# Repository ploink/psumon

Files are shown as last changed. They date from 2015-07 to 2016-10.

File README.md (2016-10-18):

# PSUmon
PSUmon is a low-cost hardware ATX power supply monitor. 
It hotplugs to any free SATA power connector and signals if voltage or ripple exceeds the ATX specification.

The PCB is designed using Eagle 5, but should import ok in version 6 and 7. 
The board is very small, so the freeware edition of eagle can be used.
The firmware for the ATtiny24A microcontroller is written in C using Atmel Studio. An ISP header is included for in-system programming and debugging.

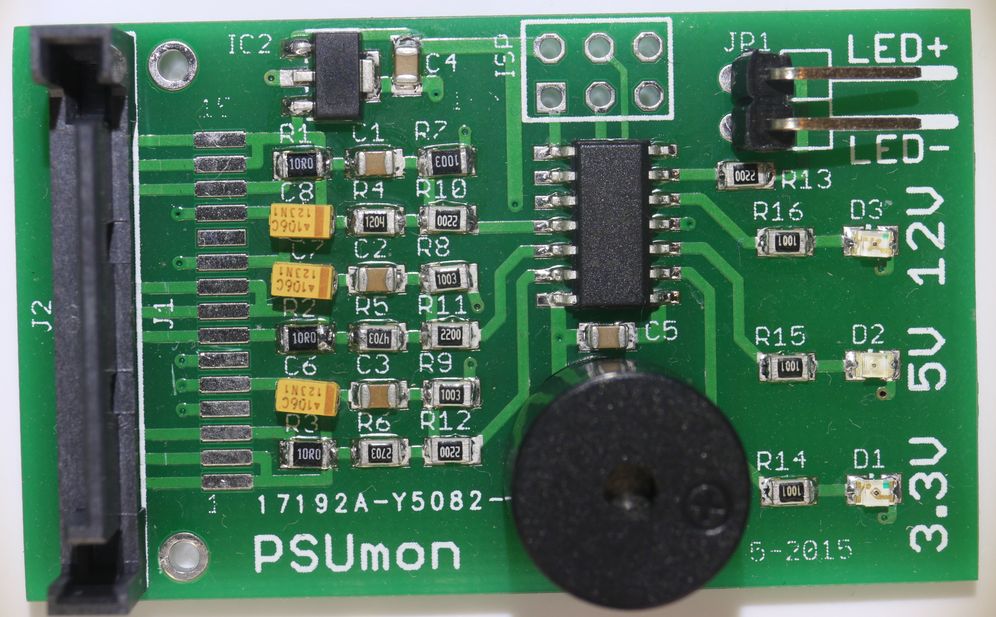
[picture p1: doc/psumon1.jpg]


Voltage tresholds are:

|Voltage |Tolerance |Ripple |LED color |
|---|---|---|---|
|3.3V | ±5% | 50mV  |GREEN |
|5V | ±5% | 50mV  |RED |
|12V | ±5% |120mV  |YELLOW |

This is how it works:
* When voltage and ripple are within limits, the corresponding LED lights continuously.
* When voltage or ripple exceeds the limit once, it blinks once every 3 seconds or so.
* When it exceeds the limit twice it blinks twice, ... and so on, up to 5x.
* When any led blinks 3x or more, the buzzer beeps 1x or more.
* The 3.3V power may not be present on every connector, in that case the green LED will be off and the voltage is ignored.
* There is a header to connect an optional external LED, for example your system power LED. It signals the worst of the three voltages.

## Parts and schematic
Most parts and values are obvious from <a href="https://raw.githubusercontent.com/ploink/psumon/master/doc/circuit.png">the schematic</a> and can be exported to a text file from within Eagle. If you want to check the gerber files, just open top.gvp and bottom.gvp in <a href="http://gerbv.geda-project.org/">gerbv</a>.

Note that the included parts.txt and also the gerber files may not be up to date!

The design includes two options for a <a href="https://raw.githubusercontent.com/ploink/psumon/master/doc/sata.jpg">SATA power connector</a>. A suitable connector with only power and no data connection is hard to find. I got mine from seller CASIBAO LED LIGHT on Aliexpress, but that is no longer available, but <a href="https://www.aliexpress.com/item/Original-new-100-SATA-interface-hard-disk-interface-socket-15P-male-180-degree-line-of-single/32738192943.html">this one</a> from Shenzhen MingSheng International Trading Co., Ltd. seems to be the same. You can also get <a href="http://www.ebay.com/itm/10-Pcs-7-15-Pin-Right-Angle-SMT-Male-Sata-Connector-For-2-5-Hard-Drive-HDD-/171720426198">this 7+15pin connector</a> from seller newdeparture2010 on Ebay and simply <a href="https://raw.githubusercontent.com/ploink/psumon/master/doc/psumon2.jpg"> cut the data connector off</a>.

To measure the voltages, the DC levels are divided down using a resistive divider to get them within range of the 1.1V reference from the ATtiny24A MCU. Using a capacitor, the AC ripple voltages are coupled directly to the same MCU pins to get a better sensitivity. This means the firmware needs to average to get the DC level and determine min/max values to get the ripple.

The 78L05 (IC2) is to make sure the MCU gets a stable 5V power even if the DUT (device under test) is very bad.

Do NOT replace the three tantalum capacitors with ceramics. The ESR is important for suppressing high frequency resonance in the power cable, but you may want to add a 100nF ceramic in parallel as is required in the <a href="http://www.formfactors.org/developer/specs/atx12v%20psdg2.01.pdf">ATX PSU design guide (pdf)</a> section 3.2.6.

## Calibration
The firmware has a provision for calibration. All you need to do after programming is to connect it to a reference supply for the first time and it wil measure and store the reference values. The PSU in one of my computers is accurate to about 1.5% so I just used that, but if you plan to sell this product, you should really make a good calibration setup.

Note that even when you use precision resistors, the 1.1V reference inside the MCU is really not accurate enough to skip the calibration step!

## To wrap it up
It is strongly recommended to protect the PCB from shorts inside your computer case. Wrapping it in 30mm diameter transparant heatshrink tubing will do the job.

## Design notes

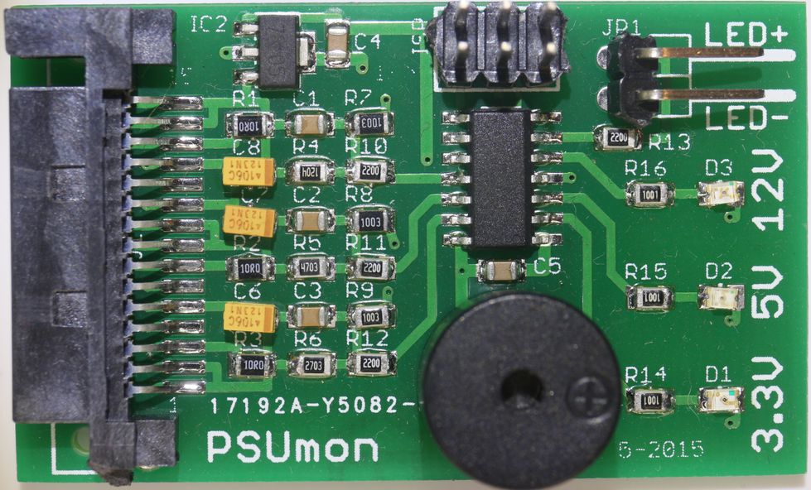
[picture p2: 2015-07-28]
doc/psumon2.jpg

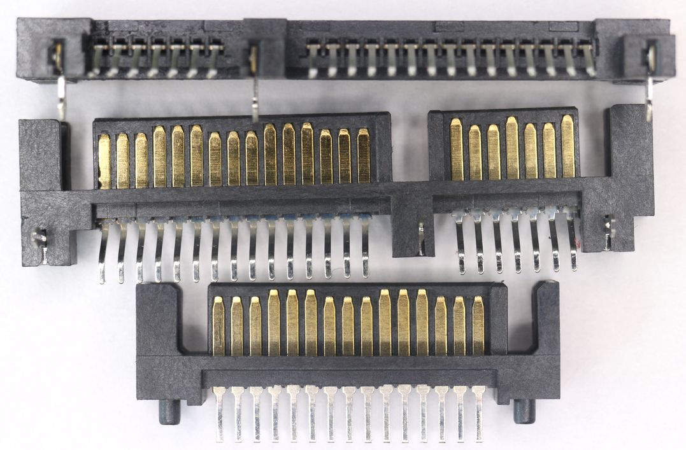
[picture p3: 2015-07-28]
doc/sata.jpg

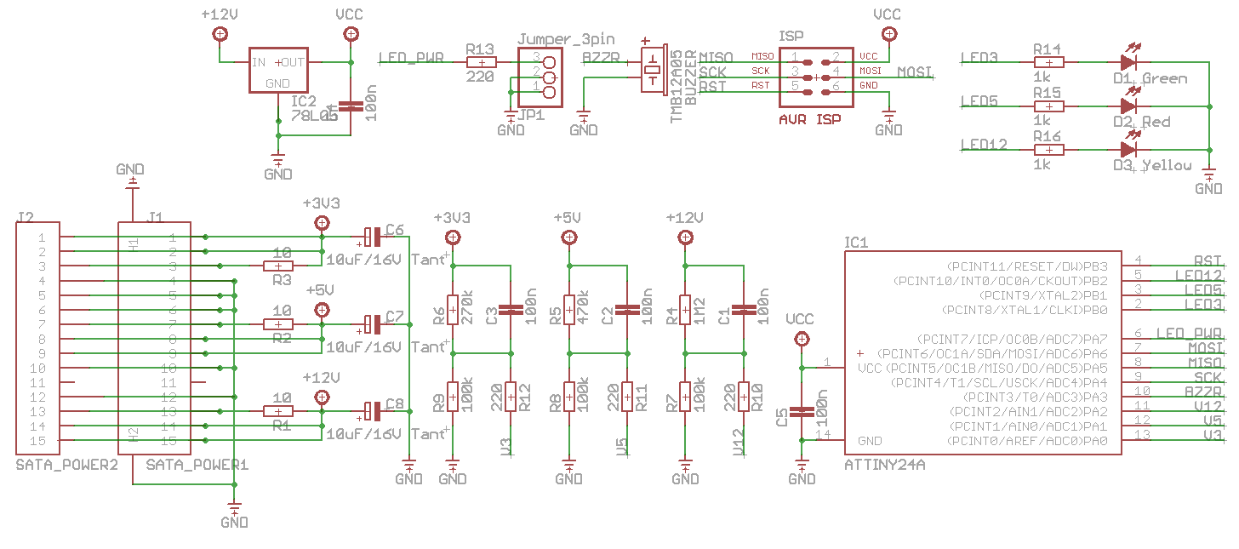
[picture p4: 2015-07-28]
doc/circuit.png

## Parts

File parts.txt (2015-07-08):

Partlist

Exported from psumon.brd at 08-07-2015 23:53:47

EAGLE Version 5.12.0 Copyright (c) 1988-2011 CadSoft

Part     Value          Package       Library  Position (mil)        Orientation

BUZZER   TMB12A05       BUZZER_12_7.6 psumon   (1200.787 246.063)    R180
C1       100n           C0805         psumon   (738.189 885.827)     R180
C2       100n           C0805         psumon   (738.189 649.606)     R180
C3       100n           C0805         psumon   (738.189 413.386)     R180
C4       100n           C0805         psumon   (826.772 1082.677)    R90
C5       100n           C0805         psumon   (1205.906 523.228)    R0
C6       10uF/16V Tant  C1206P        psumon   (570.866 413.386)     R180
C7       10uF/16V Tant  C1206P        psumon   (570.866 649.606)     R180
C8       10uF/16V Tant  C1206P        psumon   (570.866 767.717)     R180
D1       Green          D0805         psumon   (1732.283 196.85)     R0
D2       Red            D0805         psumon   (1732.283 413.386)    R0
D3       Yellow         D0805         psumon   (1732.283 629.921)    R0
IC1      ATTINY24A      SOIC14        psumon   (1209.449 750.394)    R90
IC2      78L05          SOT89         psumon   (651.575 1063.386)    R270
ISP      AVR-ISP-6VERT  AVR-ISP-6     psumon   (1200.787 1062.992)   R0
J1       SATA_POWER1    SATA_POWER1   psumon   (413.78 590.551)      R270
J2       SATA_POWER2    SATA_POWER2   psumon   (167.323 590.551)     R90
JP1      Jumper_3pin    1X03/90       psumon   (1653.543 984.252)    R270
R1       10             R0805         psumon   (590.551 885.827)     R180
R2       10             R0805         psumon   (590.551 531.496)     R180
R3       10             R0805         psumon   (590.551 295.276)     R180
R4       1M2            R0805         psumon   (738.189 767.717)     R180
R5       470k           R0805         psumon   (738.189 531.496)     R180
R6       270k           R0805         psumon   (738.189 295.276)     R180
R7       100k           R0805         psumon   (885.827 885.827)     R180
R8       100k           R0805         psumon   (885.827 649.606)     R180
R9       100k           R0805         psumon   (885.827 413.386)     R180
R10      220            R0805         psumon   (885.827 767.717)     R0
R11      220            R0805         psumon   (885.827 531.496)     R0
R12      220            R0805         psumon   (885.827 295.276)     R0
R13      220            R0805         psumon   (1574.803 748.031)    R0
R14      1k             R0805         psumon   (1574.803 196.85)     R0
R15      1k             R0805         psumon   (1574.803 413.386)    R0
R16      1k             R0805         psumon   (1574.803 629.921)    R0

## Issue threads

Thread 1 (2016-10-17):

Sata Power Connector Link

carlossless, 2016-10-17:
Hi, Awesome project. I've stumbled across it while looking for a SMD or through-hole SATA Power Connector (with no data). Yes the ones you mentioned are hard to find ;). The link you have on the readme no longer works and 404s. Did you happen to maybe find another source for these rare parts, and if so could you share them again?

Thank you!

ploink, 2016-10-18:
Hi Karolis,

I have no other source for the connector, but searching Aliexpress.com
for "sata 15p power connector" I found some, though they have the 3
contacts for each power rail merged in one pin.
https://www.aliexpress.com/item/10pcs-lot-SATA-connector-power-Interface-SATA-15P-welding-seat-SATA-plastic-shell/32710552274.html

The other option is cutting of the data part from this connector. It is
a bit of a hack, but I it works very well.
http://www.ebay.com/itm/10-Pcs-7-15-Pin-Right-Angle-SMT-Male-Sata-Connector-For-2-5-Hard-Drive-HDD-/171720426198

Best regards,
Joost.

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

--
Joost Ruijsch
Rustenburg 22
6701DV Wageningen
0317-424249
06-19752562

carlossless, 2016-10-18:
Yep, after looking again with those exact keywords I found a bunch more. Including these ones: https://www.aliexpress.com/item/10PCS-Hard-disk-interface-SATA-15P-male-connector-socket-insert-plate-90-degrees/32706493159.html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
and
https://www.aliexpress.com/item/Original-new-100-SATA-interface-hard-disk-interface-socket-15P-male-180-degree-line-of-single/32738192943.html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,searchweb201602_2_10065_10068_10069_10017_10080_10082_10081_10060_10061_10062_10056_10037_10055_10054_10033_10059_10078_10079_10073_10070_421_420_10052_10053_10050_10051,searchweb201603_7&btsid=5557b6b3-ce7a-444c-99e0-0176f6f2e174

One of them is probably compatible with the footprint you have on this board.

ploink, 2016-10-18:
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
Yes the second one looks identical to mine. I have updated the readme,
thanks.

Joost Ruijsch

carlossless, 2016-10-19:
Thank you! Closing this issue.

Closed 2016-10-19.

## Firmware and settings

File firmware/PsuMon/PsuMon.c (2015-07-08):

/*
 * PsuMon.c
 *
 * Created: 15-05-2015 15:36:21
 *  Author: joost
 */ 

#define F_CPU 8000000UL

#include <avr/io.h>
#include <util/delay.h>
#include <avr/eeprom.h>
#include "bits.h"

const char fusedata[] __attribute__ ((section (".fuse"))) = {0xE2, 0xDC, 0xFF};

byte EEMEM EE_REF3=0xff;
byte EEMEM EE_REF5=0xff;
byte EEMEM EE_REF12=0xff;


#define	LED_3V	BIT(PORTB,0)
#define	LED_5V	BIT(PORTB,1)
#define	LED_12V	BIT(PORTB,2)
#define LED_PWR	BIT(PORTA,7)
#define BUZZER	BIT(PORTA,3)
	
#define MUX_3V		0b10000000
#define MUX_5V		0b10000001
#define MUX_12V		0b10000010
#define StartADC(x)	ADMUX=MUX_##x;BIT(ADCSRA,ADSC)=1
#define GetADC(x)	while (BIT(ADCSRA,ADSC)); x=ADCH;


// Calculated calibration values. These should work OK if you are lucky
byte REF3	 =  3.3*(100.0/(100+270))*255/1.1;
byte REF5	 =  5.0*(100.0/(100+470))*255/1.1;
byte REF12 =  12.0*(100.0/(100+1200))*255/1.1;

// Max ripple values.
static const byte RIPMAX3 = 0.050*255/1.1;
static const byte RIPMAX5 = 0.050*255/1.1;
static const byte RIPMAX12 = 0.120*255/1.1;

static const word pattern[] = {0,0xffff,0x7fff,0x5fff,0x57ff,0x55ff,0x557f};

int main(void)
{	
	// Set System Clock prescaler to 1, just in case CKDIV8 fuse is programmed.
	CLKPR=128; CLKPR=0;


	// Init I/O
	DDRA=0b10001000; PORTA=0;
	DDRB=0b00000111; PORTB=0;
	DIDR0=0b00000111; // Disable digital input buffers on analog pins.	

	LED_PWR=1;		// Enable power led immediately on boot.

	byte b; byte c;  // General purpose vars.
	byte calibrate;
	word blink3=0; word blink5=0; word blink12=0; word blinkPWR=0xffff; word beep=0; word bitpos=0x8000;
	byte rip3=0; byte rip5=0; byte rip12=0;
	byte dev3=0; byte dev5=0; byte dev12=0;
	byte counter=0;

	// Read calibration values from EEPROM
	b=eeprom_read_byte(&EE_REF3);
	if (b==255) calibrate=1;
	else {
		REF3=b;
		REF5=eeprom_read_byte(&EE_REF5);
		REF12=eeprom_read_byte(&EE_REF12);
		calibrate=0;
	}
	
	// Init ADC
	ADCSRA=0b10000101;	// Enable with prescaler 32. 
	// Conversion time: 14 ADC cycles * 32 system cyles / 8MHz = 56us
	ADCSRB=0b00010000;	// ADC result left adjusted.	
	StartADC(3V);		// First conversion to init ADC.
	//GetADC(b);			// Wait for ADC to complete. Not needed because following delay.

	// PSU must settle in 500ms. When MCU starts, The 12V rail passed 4.3V brownout plus some 7805 voltage drop.
	// We guess it should be up in 300ms. If not, this results in a fault indication.
	_delay_ms(300);
	
	// Wait longer if we connect it for calibration.
    if (calibrate) _delay_ms(2000);
	
    while(1)
    {		
		counter++;

		// Init min/max values.		
		byte min3 = 255; byte min5 = 255; byte min12 = 255;
		byte max3 =   0; byte max5 =   0; byte max12 =   0;
		word sum3 =   0; word sum5 =   0; word sum12 =   0;
		
		// loop 256 times using only 8-bit counter. Sample all three voltages and get min/max/avg values.
		// Total time = 3 * conversion time (56us) * 256 = 43ms
		byte i=0; do {
			StartADC(3V);  GetADC(b);
			if (b<min3) min3=b; 
			if (b>max3) max3=b; 
			sum3+=b;
			StartADC(5V);  GetADC(b);
			if (b<min5) min5=b; 
			if (b>max5) max5=b; 
			sum5+=b;
			StartADC(12V); GetADC(b);
			if (b<min12) min12=b; 
			if (b>max12) max12=b; 
			sum12+=b;
		} while (++i);
			
		sum3>>=8; sum5>>=8;	sum12>>=8;
			
		// calculate maximum peak-peak ripple from min/max values.
		b=max3-min3;   if (b>rip3)    rip3=b;
		b=max5-min5;   if (b>rip5)    rip5=b;
		b=max12-min12; if (b>rip12)   rip12=b;
		
		// calculate deviation form reference values
  		if (sum3>REF3)   b=sum3-REF3;   else b=REF3-sum3;   if (b>dev3) dev3=b;
		if (sum5>REF5)   b=sum5-REF5;   else b=REF5-sum5;   if (b>dev5) dev5=b;
		if (sum12>REF12) b=sum12-REF12; else b=REF12-sum12; if (b>dev12) dev12=b;					

  	    if (calibrate) {
			// Device not calibrated. We should do it now if values are plausible.
			// If not then signal with 5V LED and freeze. 
			// It probably means we just programmed the chip, otherwise a hardware fault.
			if (dev3>20 || dev5>20 || dev12>20) { 
				LED_5V=1; 
				while (1); 
			}
			// Save calibration values.
			REF3=sum3; REF5=sum5; REF12=sum12;
			eeprom_write_byte(&EE_REF3,sum3);
			eeprom_write_byte(&EE_REF5,sum5);
			eeprom_write_byte(&EE_REF12,sum12);
			LED_3V=1; 
			while (1);
	    }

		if (counter==4) {
		  counter=0;		  		  
 		  // Do blinky thing
		  if (blink3&bitpos)	LED_3V=1; else LED_3V=0;
		  if (blink5&bitpos)	LED_5V=1; else LED_5V=0;
		  if (blink12&bitpos)	LED_12V=1; else LED_12V=0;
		  if (blinkPWR&bitpos)	LED_PWR=1; else LED_PWR=0;
		  if (beep&bitpos)		BUZZER=1; else BUZZER=0;
		  bitpos=bitpos>>1;
		  
		  // after end of blink sequence then ....
		  if (bitpos==0) {
			  bitpos=0x8000;

			  // calculate new blink patterns
			  b=dev12/(byte)(REF12*5/100);		// blink once for every 5% deviation.
			  c=rip12/RIPMAX12;
			  if (c>b) b=c;
			  if (b>5) b=5;
			  byte peak=b;
			  blink12=pattern[b+1];

			  b=dev5/(byte)(REF5*5/100);
			  c=rip5/RIPMAX5;
			  if (c>b) b=c;
			  if (b>5) b=5;
			  if (b>peak) peak=b;
			  blink5=pattern[b+1];

			  if (dev3>(REF3>>1)) blink3=pattern[0]; // Led off if there is no 3.3V
			  else {				  
				  b=dev3/(byte)(REF3*5/100);		 
				  c=rip3/RIPMAX3;
				  if (c>b) b=c;
				  if (b>5) b=5;
				  if (b>peak) peak=b;
				  blink3=pattern[b+1];				  
			  }
			  
			  // "peak" contains worst measurement of all
			  blinkPWR=pattern[peak+1];

		  	  if (peak<2) peak=0;
			  else peak-=2;			  			  	
			  beep=~pattern[peak+1];		  	  
			    		  
			  // reset data
			  dev3=dev5=dev12=0;
			  rip3=rip5=rip12=0;			  
		  }
		}		
    }
}

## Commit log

2015-07-05 ATX power supply monitor
    Simple PSU monitor PCB that connects to SATA power connector.
    [calc.xls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]
2015-07-08 Added lbr dru & cam
    [psumon.GBL, psumon.GBO, psumon.GBP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]
